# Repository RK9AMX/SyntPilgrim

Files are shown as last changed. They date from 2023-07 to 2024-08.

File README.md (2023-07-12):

### HF frequency synthesizer 'Pilgrim'
# Синтезатор ТПП "Пилигрим"
Разработка схемы и ПО: [Oleg 9](http://www.cqham.ru/forum/member.php?3781-Oleg-9)

Разработка печатной платы: [RK9AMX](http://www.cqham.ru/forum/member.php?2533-RK9AMX)

Обсуждение на [форуме](http://www.cqham.ru/forum/showthread.php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) cqham.ru

Синтезатор выполнен на базе микросхемы Si5351 и микроконтроллера PIC16F1787 (PIC16F887), индикатор LCD 16x2.

Файл прошивки для **PIC16F887** - 5351_PIC16F887_v07.hex

Для **PIC16F1787** - 5351_PIC16F1787_v07X.hex. С делителем на 8 для валкодера 5351_PIC16F1787_v08X_vlc div 8.hex

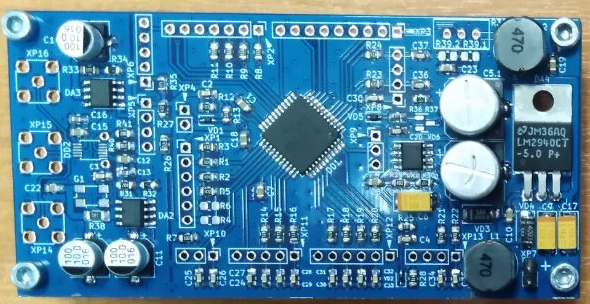
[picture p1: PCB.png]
PCB


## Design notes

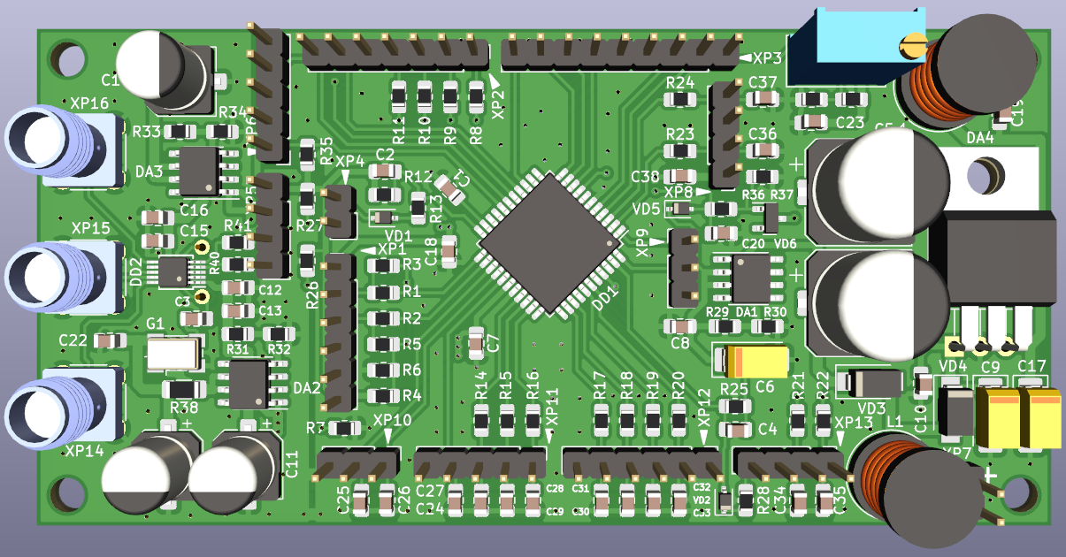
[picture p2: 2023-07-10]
top.png

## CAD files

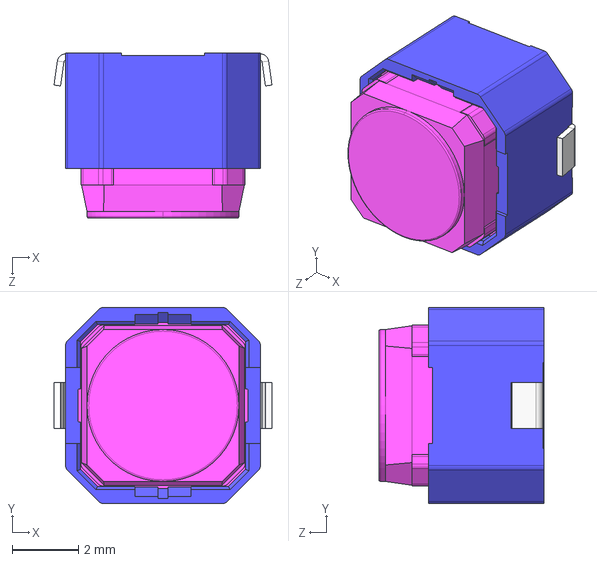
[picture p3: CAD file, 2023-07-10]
SKPMAM.STEP
6.60 x 5.94 x 5.00 mm

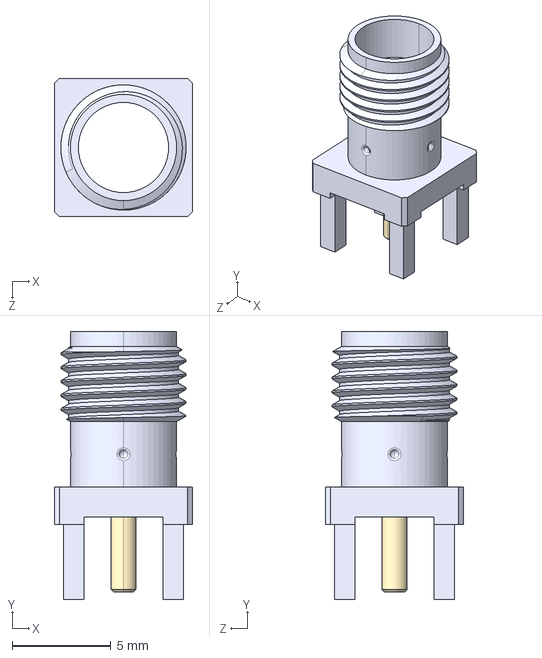
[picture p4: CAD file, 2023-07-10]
CON_SMA1.STEP
7.01 x 13.6 x 7.01 mm

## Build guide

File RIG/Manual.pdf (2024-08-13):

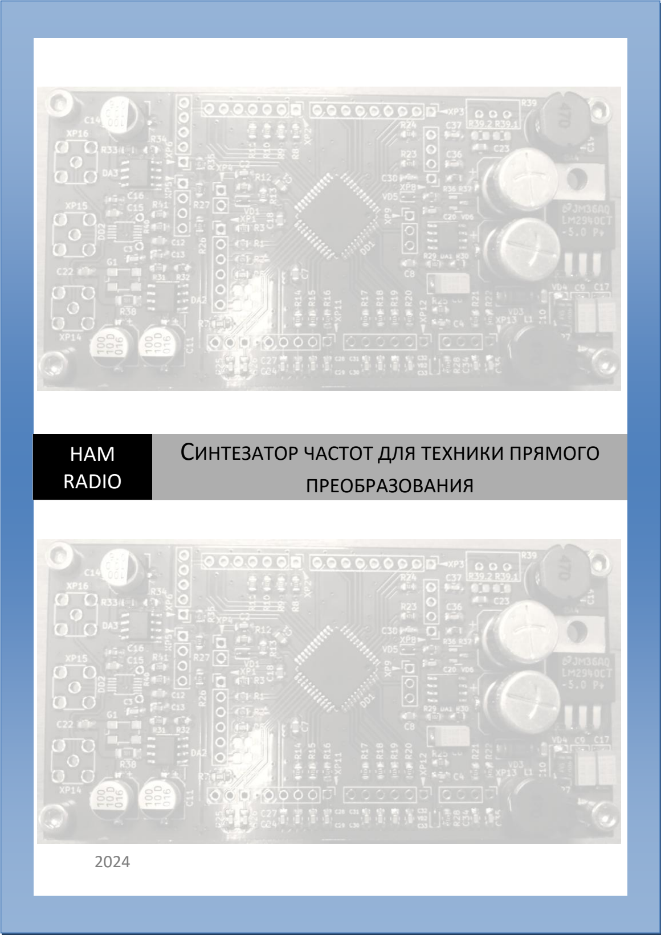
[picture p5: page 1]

2024

## HAM RADIO

## СИНТЕЗАТОР ЧАСТОТ ДЛЯ ТЕХНИКИ ПРЯМОГО

## ПРЕОБРАЗОВАНИЯ

2 | Синтезатор частот для техники прямого преобразования
| Оглавление

Введение
Синтезатор предназначен для применения в качестве гетеродина в трансивере или приёмнике прямого преобразования. Синтез частоты осуществляется микросхемой Si5351A. Перестройка частоты осуществляется валкодером.

Основные характеристики
- Напряжение питания: 9 - 12 В
- Потребляемый ток: 160 мА
- Диапазон синтезируемых частот: 12 кГц - 120 МГц
- Выходное сопротивление: 50 Ом
- Форма выходного напряжения: меандр
- Размах выходного напряжения: 3 В
- Умножение выходной частоты: 1, 2, 4 (Устанавливается в настройках)
- Индикатор: 16 сегментов, 2 строки
- Клавиатура: 12 кнопок (3 х 4)

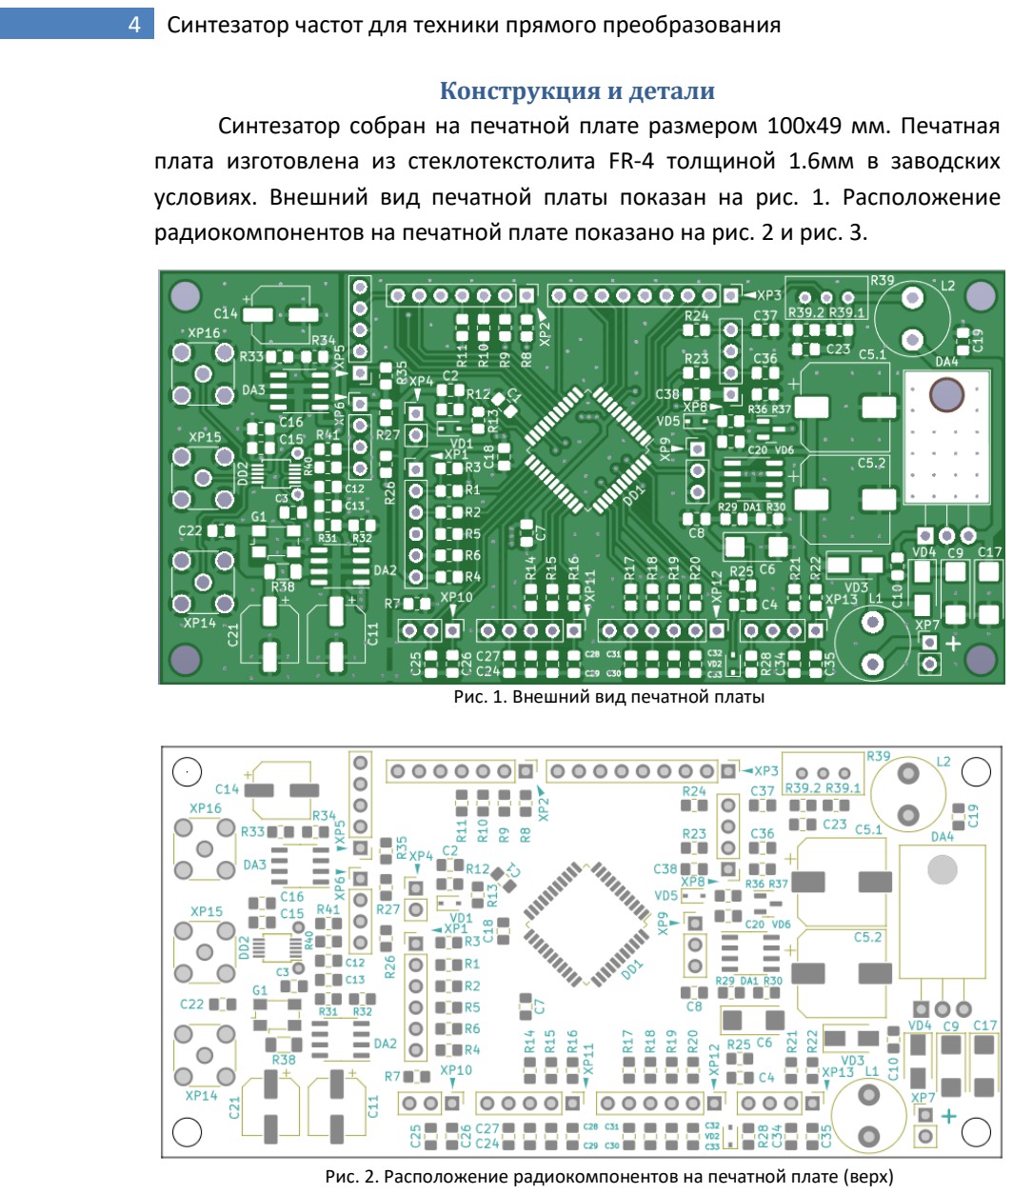
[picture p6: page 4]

Конструкция и детали
Синтезатор собран на печатной плате размером 100х49 мм. Печатная плата изготовлена из стеклотекстолита FR-4 толщиной 1.6мм в заводских условиях. Внешний вид печатной платы показан на рис. 1. Расположение радиокомпонентов на печатной плате показано на рис. 2 и рис. 3.

Рис. 1. Внешний вид печатной платы

Рис. 2. Расположение радиокомпонентов на печатной плате (верх)

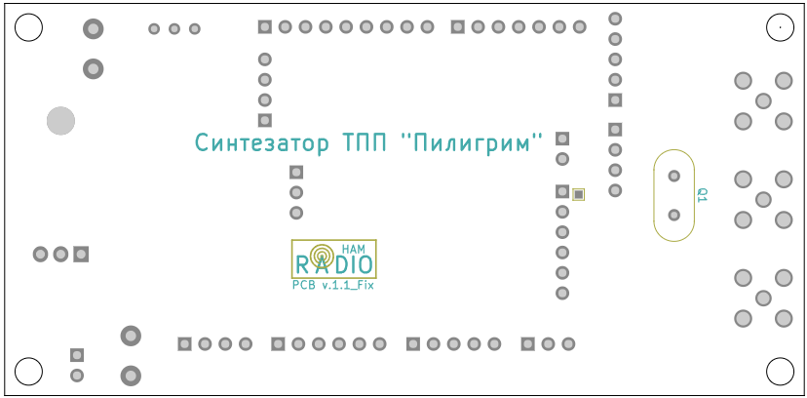
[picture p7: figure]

Рис. 3. Расположение радиокомпонентов на печатной плате (низ)

Все керамические конденсаторы SMD, типоразмер 0805. C6, C8, C17 – танталовые в корпусе 6032. С11, С14, С21 – электролитические SMD 6.3x7.7 мм. В качестве С5 применены два электролитических конденсатора суммарной эквивалентной емкостью около 1000 мкФ (C5.1 и C5.2) SMD исполнения 10х10 мм.

Все резисторы SMD, типоразмер 0805, кроме R38 – типоразмер 1206. Резистор R39 в корпусе 3296W – регулировка контрастности дисплея, может быть заменён на пару резисторов R39.1 и R39.2 типоразмера 0805. Если установлен резистор R39, то резисторы R39.1 и R 39.2 устанавливать не нужно, и наоборот.

Дроссели L1, L2 индуктивностью 20-50 мкГн и сопротивлением по постоянному току не более 1 Ом.

Диоды VD3, VD4 – любые на ток не менее 300 мА в корпусе SMA (DO-214AC). Диоды VD1, VD2, VD5 в корпусе SOD-323 с барьером шоттки. Стабилитрон VD6 в корпусе SOT-23.

Микросхемы:

- DA1-DA3 – LM317L в корпусе SO-8;
- DA4 - L7805 в корпусе TO-220;
- DD1 – PIC16F1787-I/PT в корпусе UQFN-40;
- DD2 – Si5351A-B-GT в корпусе MSOP-10.

В качестве генератора G1 можно применить кварцевый генератор в корпусе 5032 на частоту 25-27
МГц. Чтобы использовать внутренний генератор
Si5351 | на | печатной | плате | предусмотрено

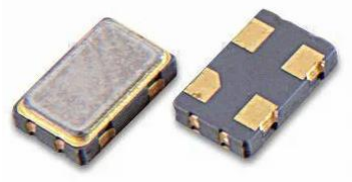
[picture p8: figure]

установочное место для кварцевого резонатора в корпусе HC49-S. Частота кварцевого резонатора должна быть 25-27 МГц. Если на плате предполагается установка кварцевого генератора, то кварцевый резонатор устанавливать не нужно, и наоборот.

Разъёмы X1-X13 – PLS на соответствующее количество контактов. Разъёмы X14-X16 – SMA вертикальные.

Клавиатура 12 копок (3х4) от телефона или самодельная с необходимым для конкретного исполнения передней панели расположением кнопок.

Индикатор жидкокристаллический 16 символов, 2
строки, | на | основе | контроллера | HD44780 | или
аналогичного. Можно применить любой, имеющий в обозначение цифры 1602. Например: WH1602A, SC1602,
HY-1602 и пр. Необходимо отметить, что у индикаторов
разных производителей может отличаться цоколёвка
разъема. Поэтому перед подключением следует ознакомиться с документацией производителя на применяемый индикатор.

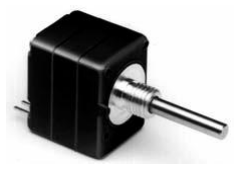
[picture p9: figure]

Валкодер может быть как самодельным, из
компьютерной | мыши | или | магнитным, | так | и
промышленного изготовления, генерирующий 32-512 импульсов на оборот. На разъёме X1 предусмотрено питание валкодера от 3.3 В и от 5 В.

Программирование микроконтроллера Программирование микроконтроллера на примере программатора PICkit3 (далее программатор) и программного обеспечениия MPLAB X IPE.

Перед началом работы с программатором необходимо провести следующие действия:

- Установить программное обеспечение MPLAB X IPE актуальной стабильной версии на ПК (драйвер программатора входит в комплект дистрибутива);
- Подключить программатор к ПК с помощью USB кабеля;
- Подключить программатор к плате изделия с помощью кабеля для внутрисхемного программирования.

Далее нужно запустить программу MPLAB X IPE (ярлык на рабочем столе). В главном меню программы выбрать пункт Settings -> Advanced mode. Появится окно (Рис. 4).

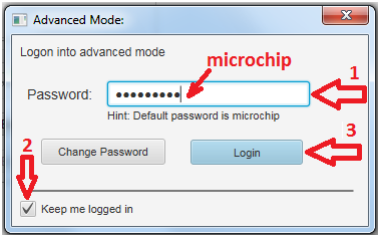
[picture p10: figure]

Рис. 4. Окно авторизации

В поле «Password» необходимо ввести пароль – microchip. Установить галочку напротив поля «Keep me logged in». Это позволит при последующих запусках программы не вводить пароль заново. Нажать кнопку «Login».

После этих действий в левой стороне окна программы должно появиться меню настроек.

Далее необходимо настроить программатор для работы с нужным микроконтроллером. Для этого в закладке «Operate» в выпадающем списке «Device» нужно выбрать микроконтроллер, с которым предполагается работа (Рис. 5). Для примера выбран PIC16F1787. Далее нужно нажать кнопку «Apply», а затем кнопку «Connect» и дождаться окончания подготовки программатора для работы с выбранным микроконтроллером.

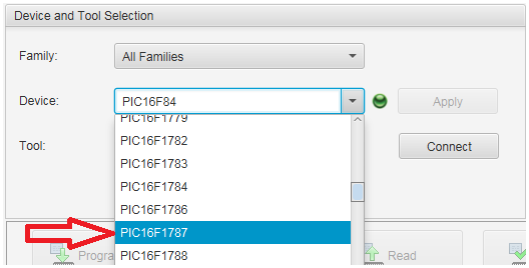
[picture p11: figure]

Рис. 5. Выбор микроконтроллера

В процессе подготовки появится окно предупреждения о том, что микроконтроллеры могут работать от напряжения 3.3V и это напряжение
необходимо | установить | в | соответствующих | настройках. | Иначе
микроконтроллер может выйти из строя (Рис. 6).

Напряжение питания микроконтроллера в схеме синтезатора 3.3 В.

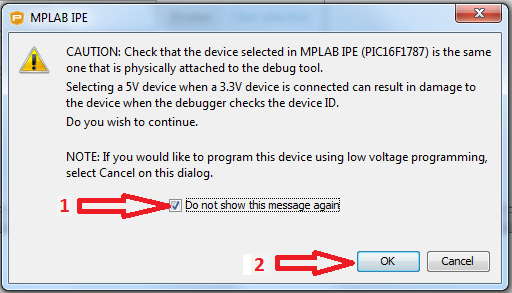
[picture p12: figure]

Рис. 6. Окно предупреждения

Нужно установить галочку напротив поля «Do not show this message again», чтобы далее об этом не предупреждать. Нажимаем кнопку «ОК» и считаем, что мы предупреждены о последствиях.

Прежде чем приступить к программированию необходимо провести настройку программатора. Для этого в меню настроек нужно выбрать вкладку «Power» (Рис. 7).

Рис. 7. Вкладка «Power»

Откроется вкладка «Power Settings». Если установить галочку напротив поля «Power Target circuit from Tool» (Рис. 8). Это позволит программировать синтезатор не подключая к нему внешнее питание. Однако рекомендуется программировать синтезатор задействовав его штатную схему питания. Поэтому указанную галочку необходимо снять.

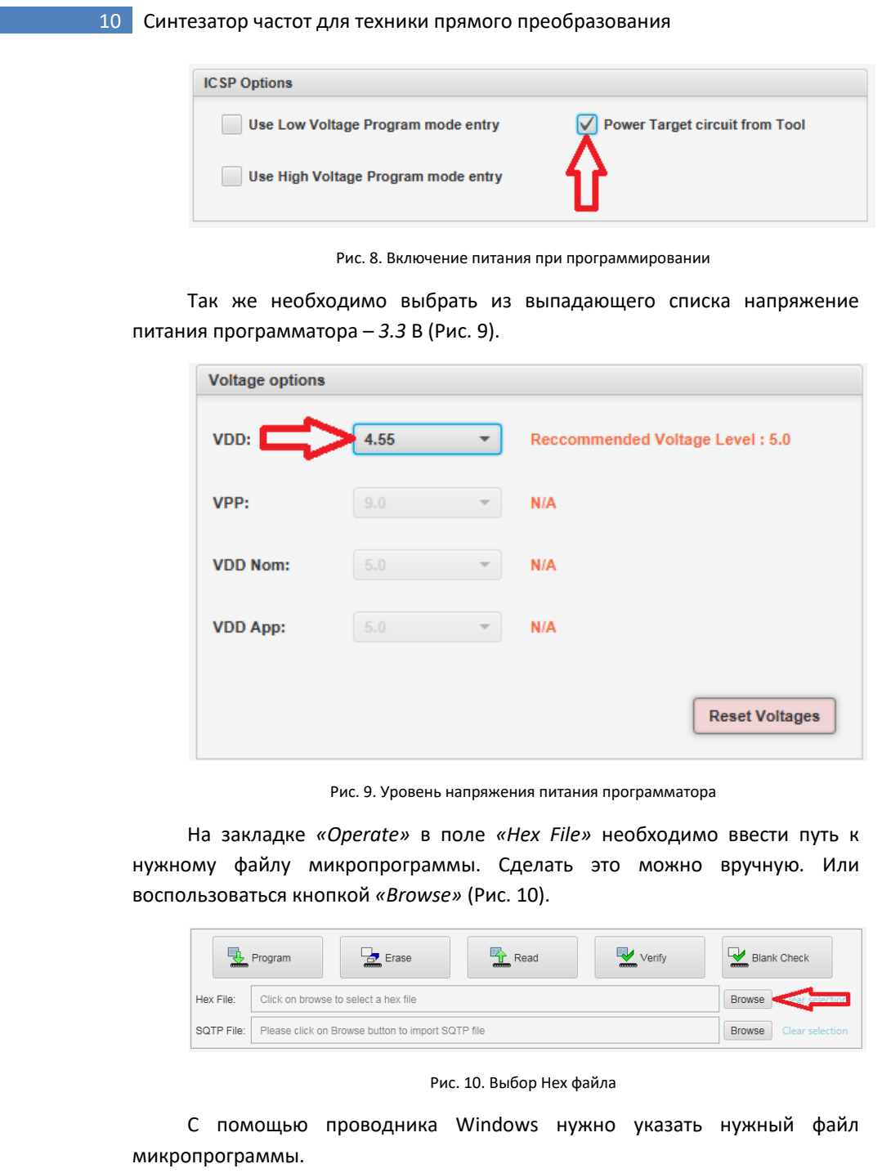
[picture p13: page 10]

Рис. 8. Включение питания при программировании

Так же необходимо выбрать из выпадающего списка напряжение питания программатора – 3.3 В (Рис. 9).

Рис. 9. Уровень напряжения питания программатора

На закладке «Operate» в поле «Hex File» необходимо ввести путь к нужному файлу микропрограммы. Сделать это можно вручную. Или воспользоваться кнопкой «Browse» (Рис. 10).

Рис. 10. Выбор Hex файла

С помощью проводника Windows нужно указать нужный файл микропрограммы.

Можно приступать к программированию микроконтроллера. Для этого нужно нажать кнопку «Program» на закладке «Operate» (Рис. 11).

Рис. 11. Кнопка «Program»

Об | успешном | завершении | операции | программирования
микроконтроллера будет свидетельствовать соответствующее сообщение в закладке «Output_IPE» (Рис. 12).

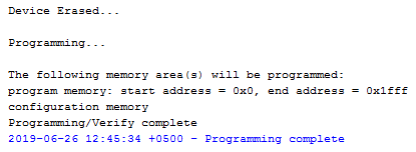
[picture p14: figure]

Рис. 12. Отчет программы

Назначение кнопок управления В режиме RX:

«1» Меняет местами действующий и запомненный набор установок диапазона. Набор установок включает в себя:

- Частоту
- Режим – CW или SSB
- Боковую полосу – верхнюю или нижнюю
- Статус аттенюатора, УВЧ и S-метра
- Включение дополнительного фильтра.

«2» Запоминает действующий набор установок диапазона.

«3» Включает режим RIT. В режиме RIT кнопка «1» включает режим XIT, кнопка «2» выключает режим RIT с сохранением текущей частоты, кнопка «3» выключает режим RIT с возвратом на частоту, которая была перед включением режима RIT.

«4» Переключает режимы cw / ssb.

«5» Переключает боковые полосы u / l.

«6» Включение / отключение S-метра.

«7» Управление УВЧ pre.

«8» Управление аттенюатором att.

«9» | Включение | дополнительного | фильтра. | Отображается | на
индикаторе точкой между режимом и боковой полосой.

«0» Вход в меню.

«*» Переключение диапазона вверх.

«#» Переключение диапазона вниз.

В режиме TX:

«1» Управление отображением безынерционной шкалы КБВ и мощности для настройки согласования передатчика с антенной.

Границы диапазонов по умолчанию Границы диапазонов можно устанавливать произвольно в меню синтезатора в переделах 1000000 – 31000000 Гц. Однако следует учитывать, чтобы частота на выходе синтезатора, которая равна:

не превышала 120000000 Гц.

Установленное по умолчанию распределение частот по диапазонам приведено в таблице 1.

Диапазон | Нижняя граница, Гц | Верхняя граница, Гц
0 | 1.799.000 | 2.001.000
1 | 3.499.000 | 3.801.000
2 | 6.999.000 | 7.201.000
3 | 10.099.000 | 10.151.000
4 | 13.999.000 | 14.351.000
5 | 18.049.000 | 18.171.000
6 | 20.999.000 | 21.451.000
7 | 24.889.000 | 24.991.000
8 | 27.999.000 | 29.701.000
GENE | 12.000 | 30.005.000
Таблица 1. Границы диапазонов по умолчанию

Ввод частоты с клавиатуры
Ввод частоты с клавиатуры используется в меню при установке границ диапазонов и других частотных установок.

Поддерживается сокращённый ввод. Например, чтобы ввести частоту 14.000.000 Гц достаточно набрать 14 → «#». Для ввода частоты 7.050.000 достаточно набрать 0705 → «#». Для ввода 1.893.210 нужно набрать 0189321 → «#».

Нажатие кнопки «*» в этом режиме перемещает курсор на одну позицию влево, обнуляя стоящую там цифру. Применяется для повторного ввода ошибочно набранной цифры.

Режим CW
В телеграфном режиме реализована функция сдвига частоты. Такое решение позволяет избавиться от помехи посредством переключения боковой полосы без потери приёма телеграфной станции. Допустим, включена верхняя боковая полоса, отображаемая на индикаторе частота будет выше выдаваемой синтезатором на величину CW shift. Значение CW shift устанавливается в настройках синтезатора равным средней частоте телеграфного фильтра. Далее в режиме CW при смене боковой полосы с верхней на нижнюю, частота синтезатора увеличивается на удвоенное значение CW shift. При смене боковой полосы с нижней на верхнюю, частота синтезатора уменьшается на удвоенное значение CW shift.

При переходе на передачу в телеграфном режиме, если в настройках синтезатора CW shift TX = On, выходная частота синтезатора становится равной отображаемой на экране, то есть частоте принимаемой станции, что позволяет формировать телеграфный сигнал непосредственно из выходного сигнала синтезатора.

Например, в настройках синтезатора CW shift = 700, CW shift TX = On, частота на выходе синтезатора 7004000 Гц, тогда в режиме CW, при включенной верхней боковой полосе на индикаторе будет отображена частота 7004700 Гц. Телеграфная станция, имеющая частоту 7004700 Гц будет приниматься с тоном 700 Гц (7004700 – 7004000 = 700). Если переключить боковую полосу с верхней на нижнюю, то частота на выходе синтезатора увеличится до 7005400 Гц и станция с частотой 7004700 Гц так же будет слышна с тоном 700 Гц (7005400 – 7004700 = 700). При переходе на передачу частота на выходе синтезатора в обоих случаях будет равна 7004700 Гц.

При установке умножения частоты синтезатора в 2 или 4 раза, во столько же умножится сдвиг выходной частоты и при последующем делении в цифровом фазовращателе смесителя примет нужное значение.

Режимы RIT и XIT
При включении режима RIT текущая частота запоминается и восстанавливается при переходе на передачу. В режиме приёма можно перестраивать частоту валкодером. Включение режима XIT меняет местами текущую и запомненную частоты и при переходе на передачу устанавливается частота, которая была в момент включения XIT.

Блокировка валкодера
Отключение валкодера осуществляется нажатием последовательности кнопок «0» → «2» (см. рис. 13). При блокировке валкодера перестройка
частоты | синтезатора | невозможна. | Однако, | остальные | функции
(переключение диапазонов, включение и отключение ATT, PRE и т.д.) доступны по нажатию соответствующих кнопок.

Рис. 13

Меню установок синтезатора Вызов меню осуществляется нажатием кнопки «0». Кнопкой «*» осуществляется перемещение курсора по пунктам меню, кнопкой «#» -выбор пункта на котором находится курсор (см. рис. 14).

Рис. 14

Назначение пунктов меню:

- F – установки синтезатора:
- XO F - установка значения частоты опорного генератора;
- Crystal cap – установка включения конденсаторов кварцевого резонатора;
- Si5151a addr – установка I

2
C адреса Si5351a;
- F out multiply – установка множителя для выходной частоты синтезатора, относительно отображаемой на индикаторе;
- CW shift - установка сдвига частоты при переходе в режим CW;
- CW shift TX – установка сдвига частоты при переходе на передачу в режиме CW.
- Vlc – установки валкодера:
- Val step – установка шага перестройки частоты валкодером;
- Val U ref – установка опорного напряжения компараторов валкодера.
- Val div – установка делителя шагов валкодера.
- BL – установка границ диапазонов;
- Io – выбор высокого или низкого логического уровня на выходах синтезатора att, pre, flt, cw, u / l при включении соответствующего режима. Активация режима отключения УВЧ pre TX off в режиме передачи.
- Sm – калибровка S-метра;
- Q – сохранение настроек и выход из меню.

Развёрнуто о некоторых настройках Частота настройки синтезатора валкодером будет изменяться на значение установленного в пункте меню «Val step» при каждом перепаде логического уровня на входах валкодера.

Установка опорного напряжения компараторов валкодера «Val U ref» актуальна при использовании самодельных валкодеров, не имеющих формирователя меандра на выходе оптопар. Например, изготовленных из компьютерной мыши. Опорное напряжение выставляется средним между значениями на выходах валкодера, когда фотоэлемент полностью освещён (отверстие в диске) и полностью затемнён (перегородка между отверстиями диска). Значение вычисляется по формуле:

Установка значения делителя шагов валкодера отличного от «1» позволит пропускать перепады логического уровня на входах валкодера. Например, при установке значения делителя «8», изменение частоты на индикаторе будет происходить только после восьмого перепада логического уровня.

В пункте меню «BL» можно задать нижнюю «Down» и верхнюю «Up» границы перестройки частоты синтезатора для каждого диапазона в пределах 1000000 – 31000000 Гц.

Выбор логических уровней для режимов att, pre, flt, cw, u осуществляется в пункте меню «Io» (см. рис. 15). Здесь можно настроить, какой логический уровень, высокий или низкий будет на выходе, при включении соответствующего режима. Например, если под буквой «u» выставить «H», то при верхней боковой полосе на выходе синтезатора USB/LSB синтезатора (контакт 3 разъёма XP11) будет напряжение логической единицы (3.3В), а при нижней боковой полосе напряжение логической единицы (0В). Если под режимом «u» выставить «L», то наоборот, при верхней боковой полосе на выходе USB/LSB будет логический ноль, а при нижней логическая единица. Аналогично для остальных выходов.

Рис. 15

Калибровка S-метра
При входе в режим калибровки индикатор приобретает вид изображённый на рис. 16.

Рис. 16

После | надписи | «Uadc» | отображается | величина | постоянного
напряжения, поступающего с детектора АРУ или детектора S-метра на вход АЦП синтезатора (контакт 4 разъёма XP11). Если нет необходимости менять настройки S-метра, то на этом этапе можно выйти из режима калибровки, нажав кнопку «*».

Для проведения калибровки нужно подать на вход приёмника или трансивера ВЧ напряжение, соответствующее показаниям S-метра и уровням указанными в столбце 3 таблицы 2. После установки напряжения соответствующего 1 баллу S-метра нужно нажать кнопку «#». Это действие сохранит калибровку и осуществит переход к следующему значению калибровки (см. рис. 17). При этом нужно подать ВЧ напряжение на вход приёмника соответствующее 2 баллам S-метра. Сохранение значения и
переход | к | следующей | уставке | осуществляется | кнопкой | «#».
Последовательность действий нужно повторить для всех калибровочных значений показаний S-метра. После S9+60dB происходит возврат в меню настроек синтезатора.

Рис. 17

Если функция S-метра не используется, то соответствующий вход нужно соединить с общим проводом синтезатора.

Уровень S-метра, балл | Уровень сигнала, dBm | Напряжение на входе (Rвх = 50 Ом), мкВ | Напряжение на входе (Rвх = 50 Ом), мкВ
1 | -121 | 0.2 | 0.24
2 | -115 | 0.4 | 0.49
3 | -109 | 0.8 | 0.98
4 | -103 | 1.6 | 1.9
5 | -97 | 3.2 | 3.9
6 | -91 | 6.3 | 7.7
7 | -85 | 12.6 | 15.4
8 | -79 | 25 | 30.7
9 | -73 | 50 | 61.3
9+10dB | -63 | 158 | 194
9+20dB | -53 | 500 | 612
9+30dB | -43 | 1580 | 1940
9+40dB | -33 | 5000 | 6120
9+50dB | -23 | 15800 | 19400
9+60dB | -13 | 50000 | 61200
Таблица 2. Соответствие уровней S-метра и уровней сигнала на входе приёмника

CAT интерфейс
В синтезаторе реализован обмен с компьютером по протоколу Kenwood (не полное соответствие, см. таблицу 3). Для взаимодействия с синтезатором в программах на ПК должны быть сделаны следующие установки:
- Модель трансивера: Kenwood TS-590;
- Скорость обмена: 57600 бод;
- Разрядность: 8 бит;
- Контроль чётности: нет;
- Стоповый бит: 1.

Команда управления состоит из двух букв, набора параметров и символа завершения команды (терминатора). Например, команда установки частоты синтезатора на 7 МГц будет состоять из элементов показанных на рис. Х

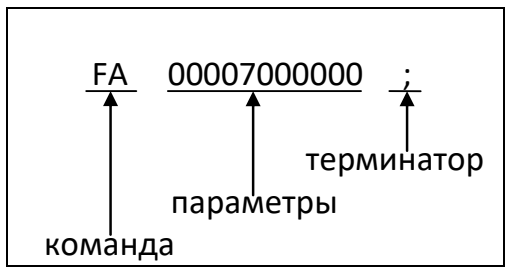
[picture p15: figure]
терминатор параметры команда

Рис. Х CAT команда

Система команд работает в режимах запрос-ответ, установка параметров. Например, команда:

- “FA00007000000;”- установка частоты синтезатора 7 МГц;
- “FA;” – запрос текущей частоты синтезатора;
- После запроса синтезатор выдаст ответ “FA00007000000;”.

В команде можно использовать как строчные, так и прописные буквы. Параметры команды используются для информации необходимой для выполнения требуемой команды. Параметры команды и количество цифр в команде предварительно определено. При настройке параметров необходимо следить за тем, чтобы не допускать ошибок. Для окончания команды используется терминатор - “;”. Его позиция в команде строго определена. Если синтаксис команды будет некорректным, то синтезатор вернёт ответ “?;”. Если возникнут ошибки в параметрах команды из-за некорректно принятых данных, то синтезатор вернёт ответ “E;”

Таблица 3. Перечень команд

BD/BU | Выбор диапазона | Параметры: P1 (Номер диапазона) 00: 1.8 МГц 01: 3.5 МГц 02: 7 МГц 03: 10 МГц 04: 14 МГц 05: 18 МГц 06: 21 МГц 07: 24 МГц 08: 28 МГц 09: GENE
Установка | 1 | 2 | 3 | 4 | 5 | 6 | 7 | 8 | 9 | 10
| B | U/D | P1 | P1 | ;
CH | Эмуляция вращение валкодера | Параметры: P1 0: Поворот валкодера на 1 шаг вверх. 1: Поворот валкодера на 1 шаг вниз.
Установка | 1 | 2 | 3 | 4 | 5 | 6 | 7 | 8 | 9 | 10
| C | H | P1 | ;
EX | Чтение и запись ячейки памяти (EEPROM) | Параметры: P1 000..255: Номер ячейки памяти P2 000..255: Значение ячейки памяти
Установка | 1 | 2 | 3 | 4 | 5 | 6 | 7 | 8 | 9 | 10
| E | X | P1 | P1 | P1 | P2 | P2 | P2 | ;
Запрос | 1 | 2 | 3 | 4 | 5 | 6 | 7 | 8 | 9 | 10
| E | X | P1 | P1 | P1 | ;
Ответ | 1 | 2 | 3 | 4 | 5 | 6 | 7 | 8 | 9 | 10
| E | X | P1 | P1 | P1 | P2 | P2 | P2 | ;

FA/FB | Установка и чтение частоты VFO-A (VFO-A = VFO-B) | Параметры: P1 - частота (11 цифр в Hz) Например, для частоты 14.195MHz формат будет такой 00014195000. Нули перед значением частоты обязательны.
Установка | 1 | 2 | 3 | 4 | 5 | 6 | 7 | 8 | 9 | 10
| F | A/B | P1 | P1 | P1 | P1 | P1 | P1 | P1 | P1
| 11 | 12 | 13 | 14 | 15 | 16 | 17 | 18 | 19 | 20
| P1 | P1 | P1 | ;
Запрос | 1 | 2 | 3 | 4 | 5 | 6 | 7 | 8 | 9 | 10
| F | A/B | ;
Ответ | 1 | 2 | 3 | 4 | 5 | 6 | 7 | 8 | 9 | 10
| F | A/B | P1 | P1 | P1 | P1 | P1 | P1 | P1 | P1
| 11 | 12 | 13 | 14 | 15 | 16 | 17 | 18 | 19 | 20
| P1 | P1 | P1 | ;
FL | Чтение и установка фильтра | Параметры: P1 0: Фильтр А 1: Фильтр Б
Установка | 1 | 2 | 3 | 4 | 5 | 6 | 7 | 8 | 9 | 10
| F | L | P1 | ;
Запрос | 1 | 2 | 3 | 4 | 5 | 6 | 7 | 8 | 9 | 10
| F | L | ;
Ответ | 1 | 2 | 3 | 4 | 5 | 6 | 7 | 8 | 9 | 10
| F | L | P1 | ;
FV | Чтение версии микропрограммного обеспечения | Параметры: P1 Чтение строки с версией программы. Например, для версии программы 1.10, ответ будет “FV1.10;”
Запрос | 1 | 2 | 3 | 4 | 5 | 6 | 7 | 8 | 9 | 10
| F | V | ;
Ответ | 1 | 2 | 3 | 4 | 5 | 6 | 7 | 8 | 9 | 10
| F | V | P1 | P1 | P1 | P1 | ;

IF | Чтение статуса синтезатора | Параметры: P1 Значение частоты 11 цифр (например: 00014155000 – 14.155kHz) P2 Пробел (5) P3 0: всегда 00000 P4 0: RIT выключена 1: RIT включена P5 0: XIT выключена 1: XIT включена P6 0: всегда 0 P7 0: всегда 00 P8 0: RX 1: TX P9 Режим модуляции: 3, 7: CW Остальные: SSB P10 0: всегда 0 P11 0: всегда 0 P12 0: всегда 0 P13 0: всегда 0 P14 0: всегда 00 P15 0: всегда 0
Запрос | 1 | 2 | 3 | 4 | 5 | 6 | 7 | 8 | 9 | 10
| I | F | ;
Ответ | 1 | 2 | 3 | 4 | 5 | 6 | 7 | 8 | 9 | 10
| I | F | P1 | P1 | P1 | P1 | P1 | P1 | P1 | P1
| 11 | 12 | 13 | 14 | 15 | 16 | 17 | 18 | 19 | 20
| P1 | P1 | P1 | P2 | P2 | P2 | P2 | P2 | P3 | P3
| 21 | 22 | 23 | 24 | 25 | 26 | 27 | 28 | 29 | 30
| P3 | P3 | P3 | P4 | P5 | P6 | P7 | P7 | P8 | P9
| 31 | 32 | 33 | 34 | 35 | 36 | 37 | 38 | 39 | 40
| P10 | P11 | P12 | P13 | P14 | P14 | P15 | ;
LK | Чтение и установка статуса блокировки валкодера | Параметры: P1 0: Блокировка вкл. 1: Блокировка откл. P2 0: всегда 0
Установка | 1 | 2 | 3 | 4 | 5 | 6 | 7 | 8 | 9 | 10
| L | K | P1 | P2 | ;
Запрос | 1 | 2 | 3 | 4 | 5 | 6 | 7 | 8 | 9 | 10
| L | K | ;
Ответ | 1 | 2 | 3 | 4 | 5 | 6 | 7 | 8 | 9 | 10
| L | K | P1 | P2 | ;

MD | Чтение и установка режима модуляции | Параметры: P1 0: Нет 1: LSB 2: USB 3: CW 4: Нет 5: Нет 6: Нет 7: CW-R 8: Нет 9: Нет
Установка | 1 | 2 | 3 | 4 | 5 | 6 | 7 | 8 | 9 | 10
| M | D | P1 | ;
Запрос | 1 | 2 | 3 | 4 | 5 | 6 | 7 | 8 | 9 | 10
| M | D | ;
Ответ | 1 | 2 | 3 | 4 | 5 | 6 | 7 | 8 | 9 | 10
| M | D | P1 | ;
PA | Чтение и установка статуса предусилителя | Параметры: P1 0: предусилитель откл. 1: предусилитель вкл. P2 0: всегда 0
Установка | 1 | 2 | 3 | 4 | 5 | 6 | 7 | 8 | 9 | 10
| P | A | P1 | ;
Запрос | 1 | 2 | 3 | 4 | 5 | 6 | 7 | 8 | 9 | 10
| P | A | ;
Ответ | 1 | 2 | 3 | 4 | 5 | 6 | 7 | 8 | 9 | 10
| P | A | P1 | P2 | ;
RA | Чтение и установка статуса аттенюатора | Параметры: P1 00: аттенюатор откл. 01: аттенюатор вкл. P2 0: всегда 00
Установка | 1 | 2 | 3 | 4 | 5 | 6 | 7 | 8 | 9 | 10
| R | A | P1 | P1 | ;
Запрос | 1 | 2 | 3 | 4 | 5 | 6 | 7 | 8 | 9 | 10
| R | A | ;
Ответ | 1 | 2 | 3 | 4 | 5 | 6 | 7 | 8 | 9 | 10
| R | A | P1 | P1 | P2 | P2 | ;
RM | Чтение значения КСВ | Параметры: P1 1: всегда 1 P2 0010…0099: Значение КСВ Например, при КСВ = 1.3 ответ будет “RM10013;”
Запрос | 1 | 2 | 3 | 4 | 5 | 6 | 7 | 8 | 9 | 10
| R | M | ;
Ответ | 1 | 2 | 3 | 4 | 5 | 6 | 7 | 8 | 9 | 10
| R | M | P1 | P2 | P2 | P2 | P2 | ;

RT | Чтение и установка статуса расстройки (RIT) | Параметры: P1 0: RIT откл.
| 1 | 2 | 3 | 4 | 5 | 6 | 7 | 8 | 9 | 10
| R | T | P1 | ; | | | | | | | 1: RIT вкл. Установка
Запрос | 1 | 2 | 3 | 4 | 5 | 6 | 7 | 8 | 9 | 10
| R | T | ;
Ответ | 1 | 2 | 3 | 4 | 5 | 6 | 7 | 8 | 9 | 10
| R | T | P1 | ;
RX | Установка режима «приём» | Параметры: Нет параметров.
Установка | 1 | 2 | 3 | 4 | 5 | 6 | 7 | 8 | 9 | 10
| R | X | ;
SM | Чтение значения S-метра | Параметры: P1 0: всегда 0 P2 0000..0030: показания S-метра
Запрос | 1 | 2 | 3 | 4 | 5 | 6 | 7 | 8 | 9 | 10
| S | M | P1 | ;
Ответ | 1 | 2 | 3 | 4 | 5 | 6 | 7 | 8 | 9 | 10
| S | M | P1 | P2 | P2 | P2 | P2 | ;
SR | Рестарт синтезатора | Параметры: P1 0: всегда 1
Установка | 1 | 2 | 3 | 4 | 5 | 6 | 7 | 8 | 9 | 10
| S | R | P1 | ;
TX | Установка режима «передача» | Параметры: P1
| 1 | 2 | 3 | 4 | 5 | 6 | 7 | 8 | 9 | 10
| T | X | P1 | ; | | | | | | | 0: всегда 0 Установка
XT | Чтение и установка статуса расстройки (XIT) | Параметры: P1 0: XIT откл.
| 1 | 2 | 3 | 4 | 5 | 6 | 7 | 8 | 9 | 10
| X | T | P1 | ; | | | | | | | 1: XIT вкл. Установка
Запрос | 1 | 2 | 3 | 4 | 5 | 6 | 7 | 8 | 9 | 10
| X | T | ;
Ответ | 1 | 2 | 3 | 4 | 5 | 6 | 7 | 8 | 9 | 10
| X | T | P1 | ;

RIG Pilgrim – общее описание программы Программа RIG Pilgrim (далее программа) предназначена для управления и настройки синтезатора. Управление и настройка синтезатора осуществляется по CAT интерфейсу. Система команд интерфейса описана в этом документе ранее. Программа позволяет управлять частотой (изменять в пределах диапазона, переключать диапазоны), аттенюатором, УВЧ, модуляцией и др. Из программы возможны чтение и запись памяти EEPROM для настройки параметров синтезатора. Программа не требует установки. Однако, её следует размещать в отдельном каталоге. В этом же каталоге буду храниться настройки программы и языковые пакеты.

RIG Pilgrim – внешний вид и описание интерфейса Внешний вид окна при запуске программы показан на рис. 18.

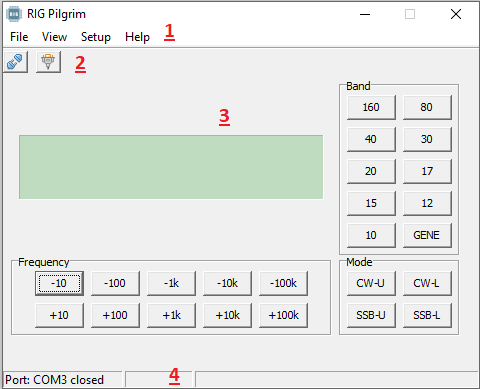
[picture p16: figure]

Рис. 18. Внешний вид программы при запуске

Окно программы делится на:

1. Основное меню;
2. Панель инструментов;
3. Панель управления;
4. Строку состояния.

Из основного меню доступно управление всеми функциями программы. Функции открытия и настройки COM порта для удобства вынесены на панель инструментов. На панели управления, после успешного подключения к синтезатору, отображается текущее синтезатора и активируются кнопки управления синтезатором.

RIG Pilgrim – настройка COM порта Для настройки COM порта выберите в меню → Setup → Serial port или

нажмите соответствующую кнопку Port Settings на панели инструментов. Появится окно установок COM порта (см. рис. 19).

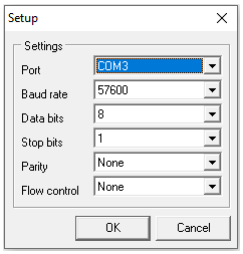
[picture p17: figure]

Рис. 19. Установки COM порта

Здесь нужно выбрать COM порт (виртуальный COM порт), к которому подключен трансивер. Скорость обмена нужно установить 57600 бод. Остальные установки порта оставить по умолчанию.

Если COM порт настроен правильно и нет неисправностей с

подключением, то после нажатия кнопки Open Port (меню → File → Open Port) произойдёт подключение трансивера к компьютеру и начнётся обмен по CAT интерфейсу.

RIG Pilgrim – элементы панели управления После успешного подключения окно программы примет вид показанный на рис. 20.

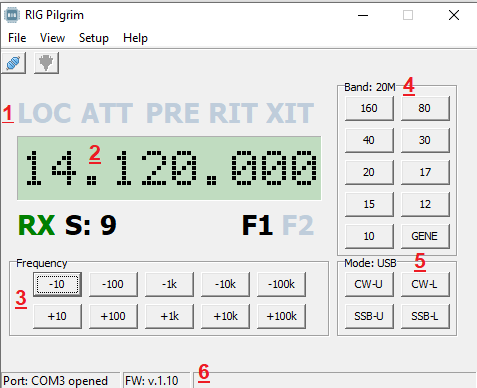
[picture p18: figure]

Рис. 20. Элементы панели управления

1. Индикация и управление функциями трансивера. Щелчок мыши по надписи приведёт к активации / деактивации выбранной функции. Например, клик мыши по надписи LOC приведёт к блокировке изменения частоты (отключению валкодера). Клик мыши по надписи RX переведёт трансивер на передачу. Надпись при этом поменяется на TX. Активация XIT невозможна, пока не будет активирована RIT.
2. Индикация установленной частоты. Частоту можно изменять колёсиком мыши, если указатель мыши находится внутри окна программы.
3. Кнопки изменения частоты.
4. Кнопки выбора диапазона.
5. Кнопки выбора модуляции и боковой полосы.
6. Строка состояния отображает открытый COM порт, версию прошивки и ошибки, возникающие при обмене командами. Если ошибок нет, то поле остаётся не заполненное. Появление ошибок свидетельствует о ненадёжном соединении трансивера с ПК.

RIG Pilgrim – элементы панели установок синтезатора Чтобы перейти к виду программы с установками синтезатора выберите пункт меню → View → RIG configuration, при этом окно программы примет вид изображённый на рис. 21.

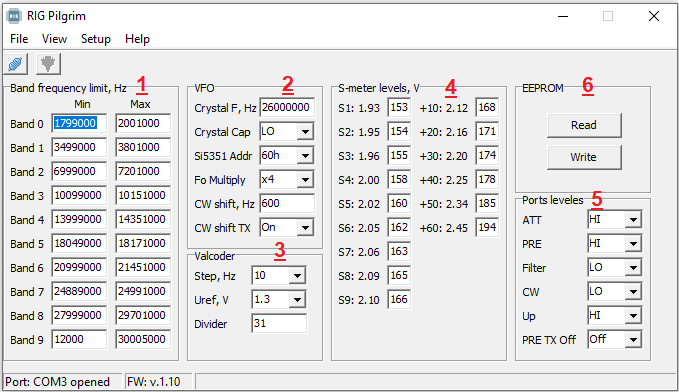
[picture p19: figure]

Рис. 21. Панель установок синтезатора

1. Установка границ диапазонов.
2. Установки гетеродина и опорного генератора.
3. Установки валкодера.
4. Константы уставок S-метра. Градуировку S-метра удобнее производить через меню синтезатора.
5. Установка активных уровней портов.
6. Кнопки чтения и записи установок в память синтезатора.

При выборе вида программы с панелью установок синтезатора происходит чтение EEPROM. Пока читается EEPROM, доступ к функциям программы недоступен.

Сохранить в файл или загрузить из файла установки синтезатора можно выбрав соответствующий пункт меню File. Файлы установок имеют расширение .cfr.

Возврат окна программы к виду панели управления осуществляется выбором пункта меню → View → CAT mode.

При изменении установок синтезатора будьте внимательны! Если вы не понимаете как нужно изменять установки, то не следует этого делать.

RIG Pilgrim – прочие функции Чтобы изменить языковые настройки нужно выбрать пункт меню → Setup → Language. Программа поддерживает два языковых пакета: Русский и English. Файлы с языковыми пакетами должны находиться в папке с программой.

Выбор пункта меню → Help → Manual откроет данное руководство. Файл руководства должен находиться в папке с программой.

Версия документа и история изменений

Текущая версия документа: v. 1

Версия документа v.1

Дата создания документа: 09.08.2024

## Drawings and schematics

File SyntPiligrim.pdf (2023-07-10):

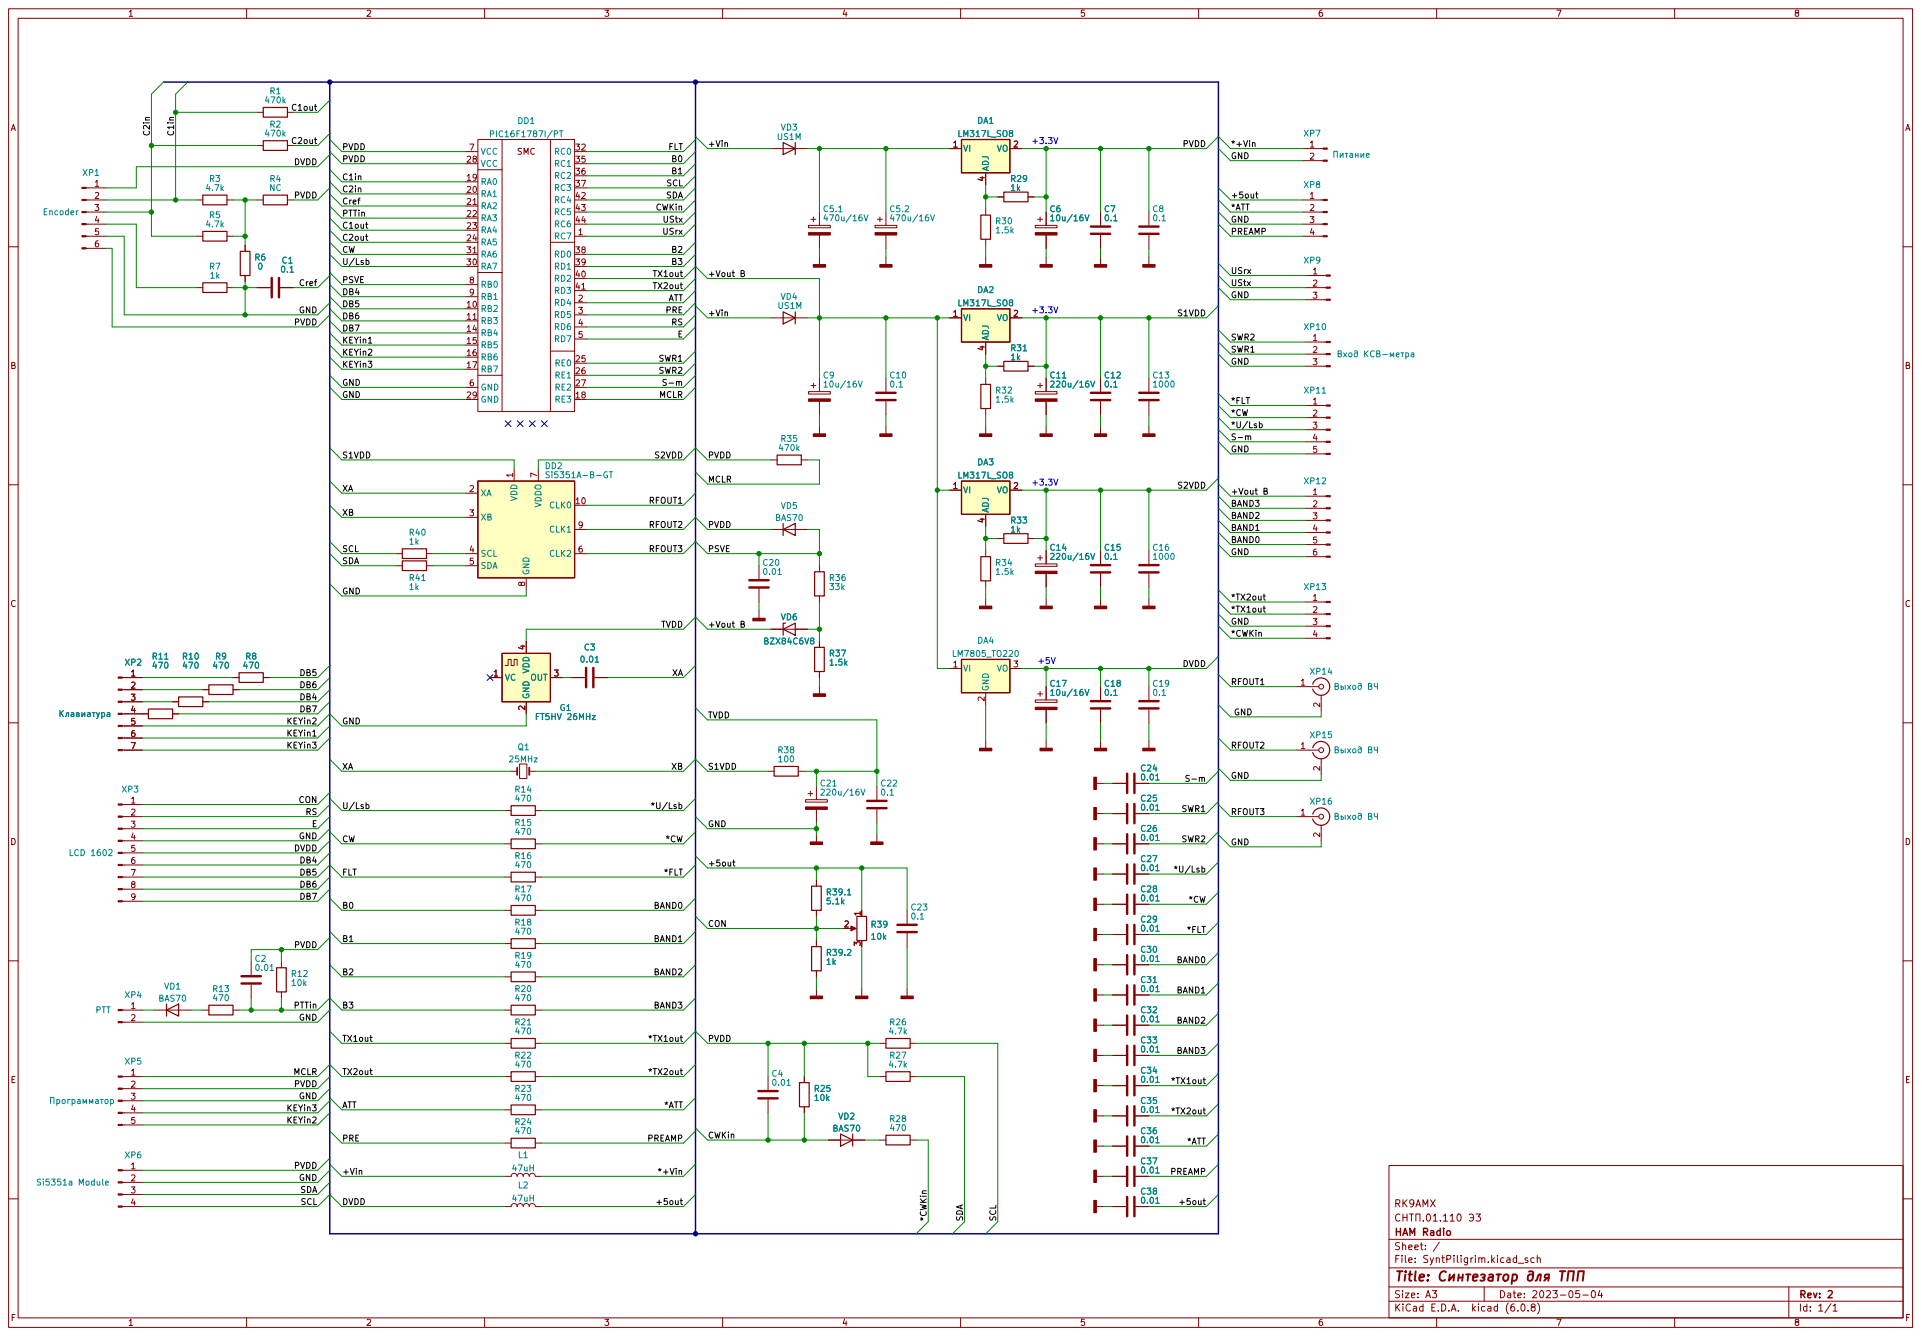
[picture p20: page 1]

File: SyntPiligrim.kicad_sch Sheet: / HAM Radio

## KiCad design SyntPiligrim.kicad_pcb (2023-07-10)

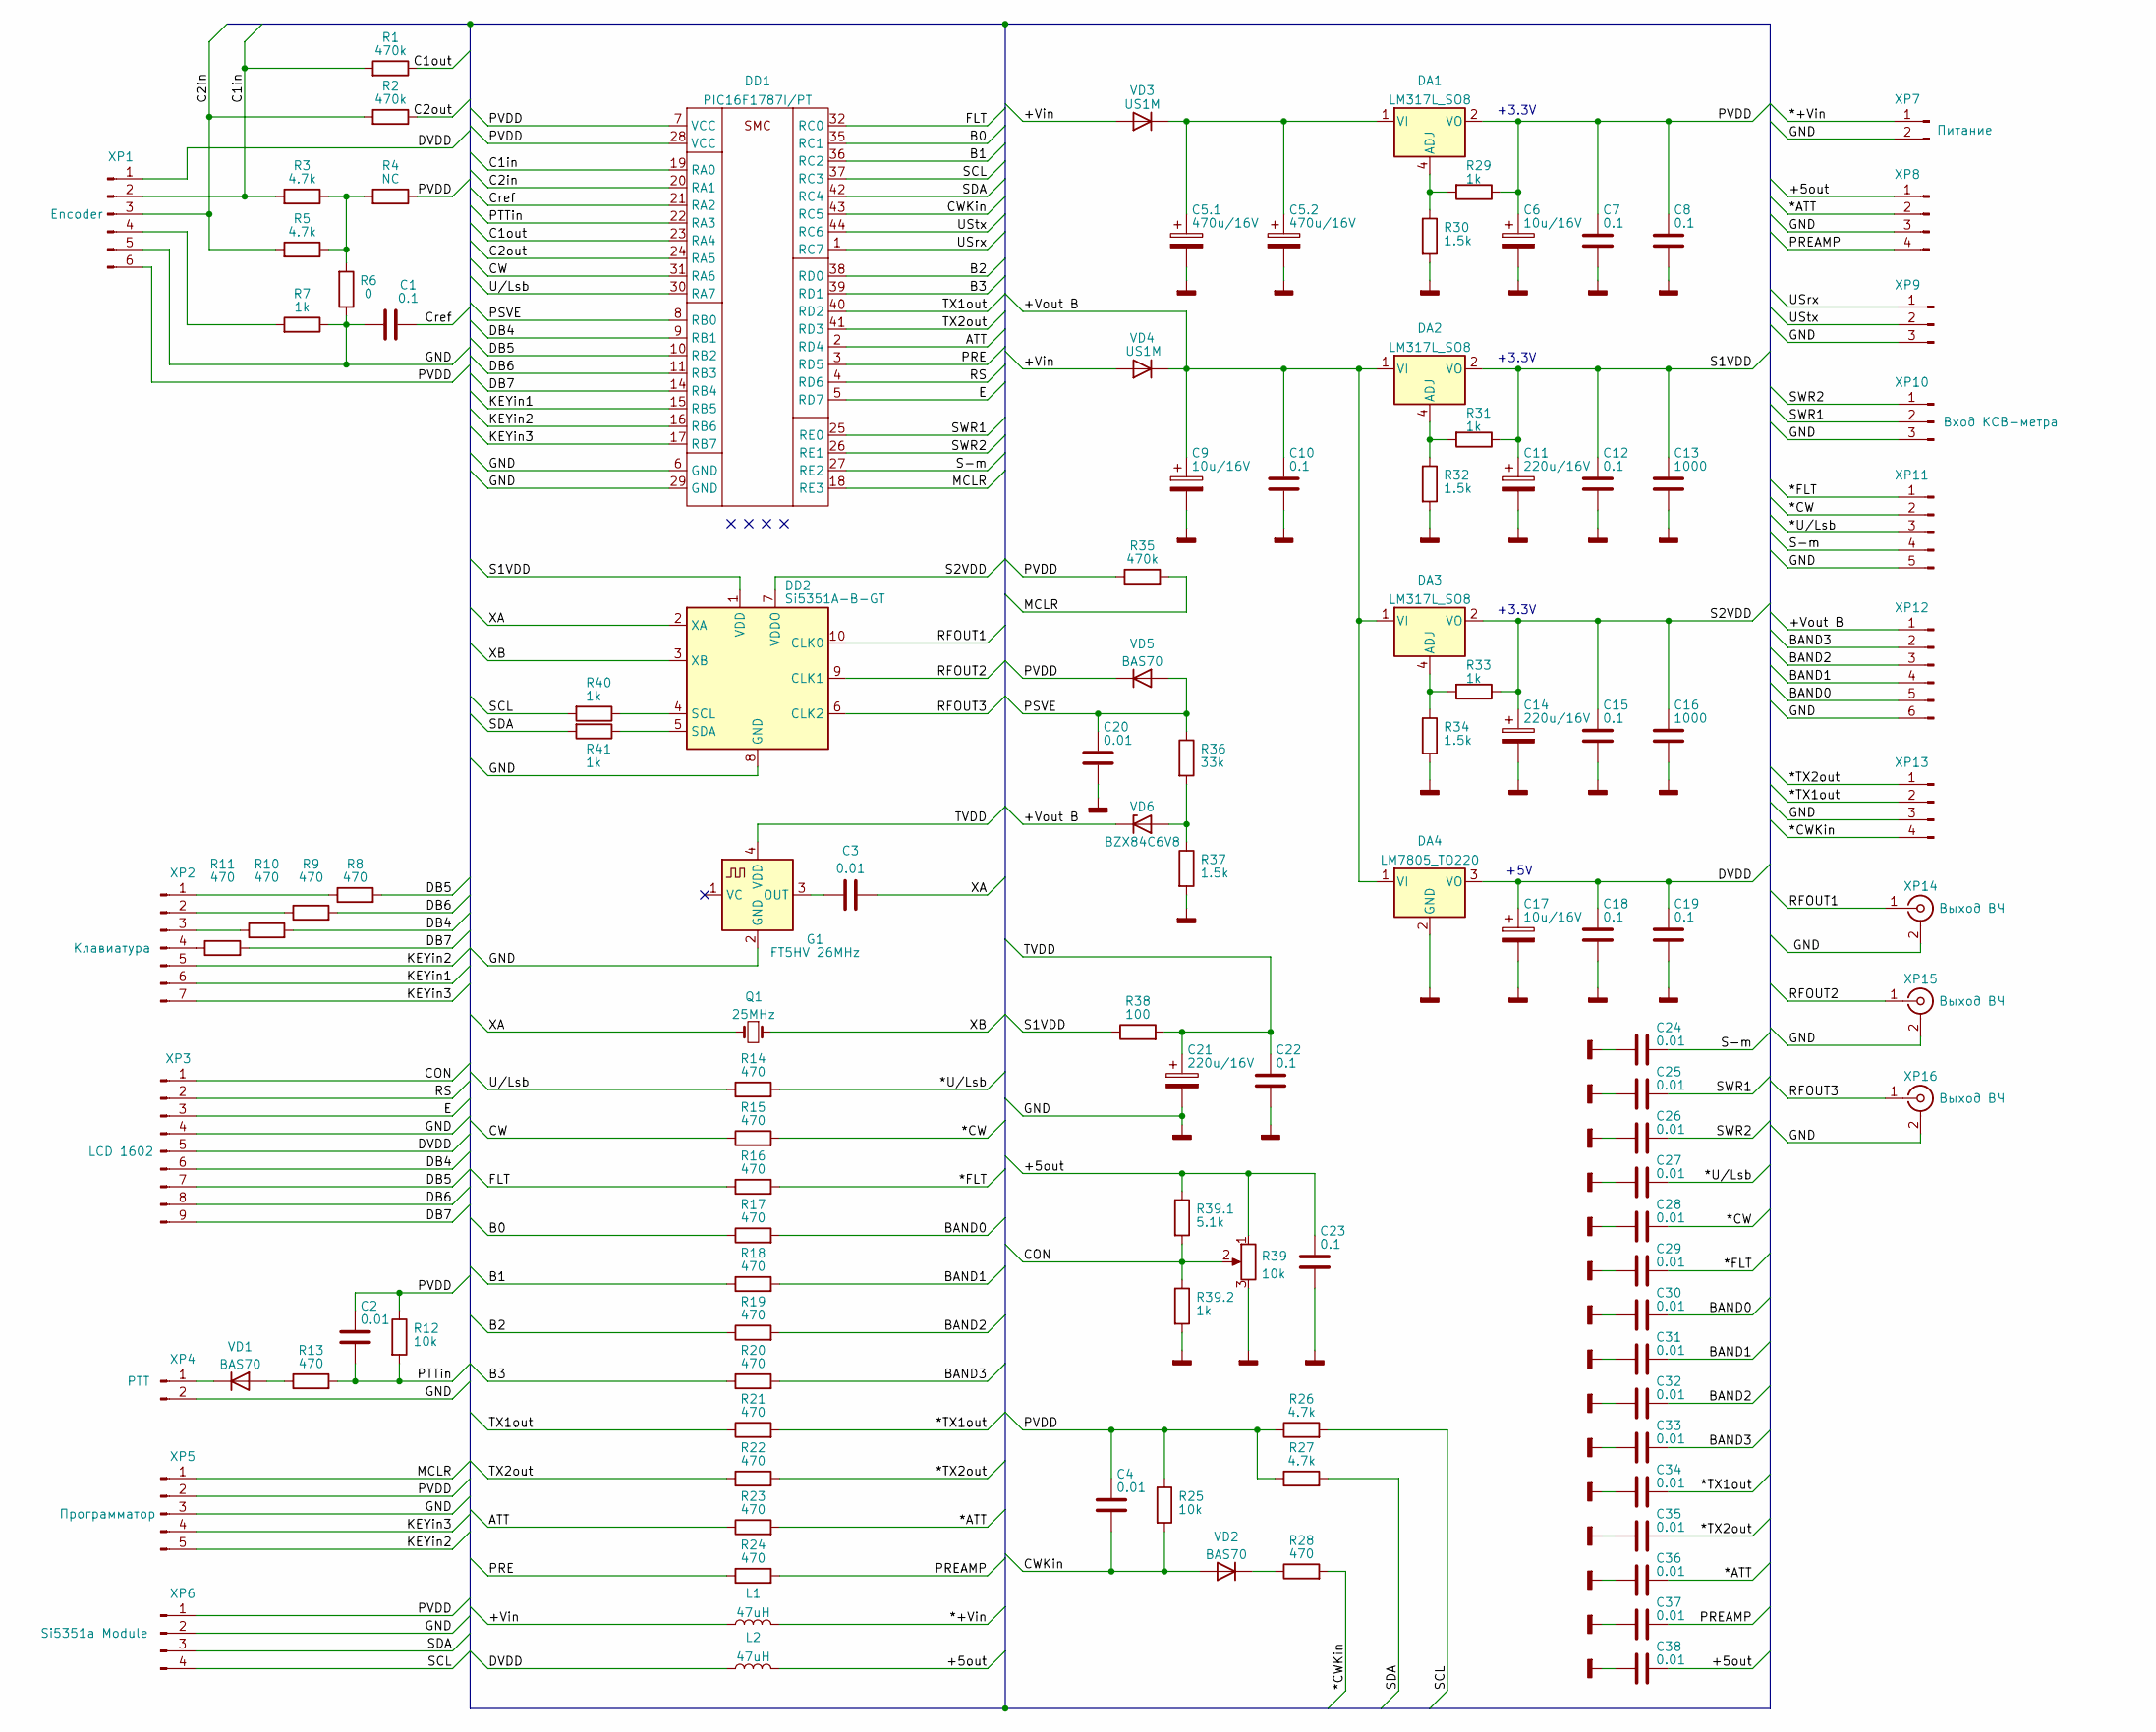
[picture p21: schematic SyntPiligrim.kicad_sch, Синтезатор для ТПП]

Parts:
C1, C7, C8, C10, C12, C15, C18, C19, C22, C23: 0.1; C_0805_2012Metric_Pad1.18x1.45mm_HandSolder
C2, C3, C4, C20, C24, C25, C26, C27, C28, C29, C30, C31, C32, C33, C34, C35, C36, C37, C38: 0.01; C_0805_2012Metric_Pad1.18x1.45mm_HandSolder
C5.1, C5.2: 470u/16V; CP_Elec_10x10
C6, C9, C17: 10u/16V; CP_EIA-6032-28_Kemet-C_Pad2.25x2.35mm_HandSolder
C11, C14, C21: 220u/16V; CP_Elec_6.3x7.7
C13, C16: 1000; C_0805_2012Metric_Pad1.18x1.45mm_HandSolder
DA1, DA2, DA3: LM317L_SO8; SOIC-8_3.9x4.9mm_P1.27mm
DA4: LM7805_TO220; TO-220-3_Horizontal_TabDown
DD1: PIC16F1787I/PT; LQFP-44_10x10mm_P0.8mm
DD2: Si5351A-B-GT; MSOP-10_3x3mm_P0.5mm
G1: FT5HV 26MHz; Oscillator_SMD_Fox_FT5H_5.0x3.2mm
L1, L2: 47uH; L_Radial_D8.7mm_P5.00mm_Fastron_07HCP
Q1: 25MHz; Crystal_HC49-4H_Vertical
R1, R2, R35: 470k; R_0805_2012Metric_Pad1.20x1.40mm_HandSolder
R3, R5, R26, R27: 4.7k; R_0805_2012Metric_Pad1.20x1.40mm_HandSolder
R4: NC; R_0805_2012Metric_Pad1.20x1.40mm_HandSolder
R6: 0; R_0805_2012Metric_Pad1.20x1.40mm_HandSolder
R7, R29, R31, R33, R39.2, R40, R41: 1k; R_0805_2012Metric_Pad1.20x1.40mm_HandSolder
R8, R9, R10, R11, R13, R14, R15, R16, R17, R18, R19, R20, R21, R22, R23, R24, R28: 470; R_0805_2012Metric_Pad1.20x1.40mm_HandSolder
R12, R25: 10k; R_0805_2012Metric_Pad1.20x1.40mm_HandSolder
R30, R32, R34, R37: 1.5k; R_0805_2012Metric_Pad1.20x1.40mm_HandSolder
R36: 33k; R_0805_2012Metric_Pad1.20x1.40mm_HandSolder
R38: 100; R_1206_3216Metric_Pad1.30x1.75mm_HandSolder
R39: 10k; Potentiometer_Bourns_3296W_Vertical
R39.1: 5.1k; R_0805_2012Metric_Pad1.20x1.40mm_HandSolder
VD1, VD2, VD5: BAS70; D_SOD-323
VD3, VD4: US1M; D_SMA
VD6: BZX84C6V8; SOT-23
XP1: Encoder; PinHeader_1x06_P2.54mm_Vertical
XP2: Клавиатура; PinHeader_1x07_P2.54mm_Vertical
XP3: LCD 1602; PinHeader_1x09_P2.54mm_Vertical
XP4: PTT; PinHeader_1x02_P2.54mm_Vertical
XP5: Программатор; PinHeader_1x05_P2.54mm_Vertical
XP6: Si5351a Module; PinHeader_1x04_P2.54mm_Vertical
XP7: Питание; PinHeader_1x02_P2.54mm_Vertical
XP8, XP13: c; PinHeader_1x04_P2.54mm_Vertical
XP9: Conn_01x03_Male; PinHeader_1x03_P2.54mm_Vertical
XP10: Вход КСВ-метра; PinHeader_1x03_P2.54mm_Vertical
XP11: c; PinHeader_1x05_P2.54mm_Vertical
XP12: c; PinHeader_1x06_P2.54mm_Vertical
XP14, XP15, XP16: Выход ВЧ; SMA_Wurth_60312002114503_Vertical

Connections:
/*+Vin: L1.2, XP7.1
/*ATT: C36.1, R23.2, XP8.2
/*CW: C28.1, R15.2, XP11.2
/*CWKin: R28.2, XP13.4
/*FLT: C29.1, R16.2, XP11.1
/*TX1out: C34.1, R21.2, XP13.2
/*TX2out: C35.1, R22.2, XP13.1
/*U/Lsb: C27.1, R14.2, XP11.3
/+5out: C23.1, C38.1, L2.2, R39.1, R39.1.1, XP8.1
/+Vin: L1.1, VD3.2 (A), VD4.2 (A)
/+Vout B: C9.1, C10.1, DA2.1 (VI), DA3.1 (VI), DA4.1 (VI), VD4.1 (K), VD6.3 (K), XP12.1
/ATT: DD1.2 (RD4), R23.1
/B0: DD1.35 (RC1), R17.1
/B1: DD1.36 (RC2), R18.1
/B2: DD1.38 (RD0), R19.1
/B3: DD1.39 (RD1), R20.1
/BAND0: C30.1, R17.2, XP12.5
/BAND1: C31.1, R18.2, XP12.4
/BAND2: C32.1, R19.2, XP12.3
/BAND3: C33.1, R20.2, XP12.2
/C1in: DD1.19 (RA0), R1.2, R3.2, XP1.2
/C1out: DD1.23 (RA4), R1.1
/C2in: DD1.20 (RA1), R2.2, R5.2, XP1.3
/C2out: DD1.24 (RA5), R2.1
/CON: R39.2, R39.1.2, R39.2.1, XP3.1
/CW: DD1.31 (RA6), R15.1
/CWKin: C4.2, DD1.43 (RC5), R25.2, VD2.2 (A)
/Cref: C1.2, DD1.21 (RA2)
/DB4: DD1.9 (RB1), R10.2, XP3.6
/DB5: DD1.10 (RB2), R8.2, XP3.7
/DB6: DD1.11 (RB3), R9.2, XP3.8
/DB7: DD1.14 (RB4), R11.2, XP3.9
/DVDD: C17.1, C18.1, C19.1, DA4.3 (VO), L2.1, XP1.1, XP3.5
/E: DD1.5 (RD7), XP3.3
/FLT: DD1.32 (RC0), R16.1
/KEYin1: DD1.15 (RB5), XP2.6
/KEYin2: DD1.16 (RB6), XP2.5, XP5.5
/KEYin3: DD1.17 (RB7), XP2.7, XP5.4
/MCLR: DD1.18 (RE3), R35.2, XP5.1
/PRE: DD1.3 (RD5), R24.1
/PREAMP: C37.1, R24.2, XP8.4
/PSVE: C20.1, DD1.8 (RB0), R36.1, VD5.2 (A)
/PTTin: C2.2, DD1.22 (RA3), R12.2, R13.2
/PVDD: C2.1, C4.1, C6.1, C7.1, C8.1, DA1.2 (VO), DA1.3 (VO), DA1.6 (VO), DA1.7 (VO), DD1.7 (VCC), DD1.28 (VCC), R4.1, R12.1, R25.1, R26.1, R27.1, R29.1, R35.1, VD5.1 (K), XP1.6, XP5.2, XP6.1
/RFOUT1: DD2.10 (CLK0), XP14.1 (In)
/RFOUT2: DD2.9 (CLK1), XP15.1 (In)
/RFOUT3: DD2.6 (CLK2), XP16.1 (In)
/RS: DD1.4 (RD6), XP3.2
/S1VDD: C11.1, C12.1, C13.1, DA2.2 (VO), DA2.3 (VO), DA2.6 (VO), DA2.7 (VO), DD2.1 (VDD), R31.1, R38.1
/S2VDD: C14.1, C15.1, C16.1, DA3.2 (VO), DA3.3 (VO), DA3.6 (VO), DA3.7 (VO), DD2.7 (VDDO), R33.1
/S-m: C24.1, DD1.27 (RE2), XP11.4
/SCL: DD1.37 (RC3), R26.2, R40.2, XP6.4
/SDA: DD1.42 (RC4), R27.2, R41.2, XP6.3
/SWR1: C25.1, DD1.25 (RE0), XP10.2
/SWR2: C26.1, DD1.26 (RE1), XP10.1
/TVDD: C21.1, C22.1, G1.4 (VDD), R38.2
/TX1out: DD1.40 (RD2), R21.1
/TX2out: DD1.41 (RD3), R22.1
/USrx: DD1.1 (RC7), XP9.1
/UStx: DD1.44 (RC6), XP9.2
/U/Lsb: DD1.30 (RA7), R14.1
/XA: C3.2, DD2.2 (XA), Q1.2
/XB: DD2.3 (XB), Q1.1
GNDD: C1.1, C5.1.2, C5.2.2, C6.2, C7.2, C8.2, C9.2, C10.2, C11.2, C12.2, C13.2, C14.2, C15.2, C16.2, C17.2, C18.2, C19.2, C20.2, C21.2, C22.2, C23.2, C24.2, C25.2, C26.2, C27.2, C28.2, C29.2, C30.2, C31.2, C32.2, C33.2, C34.2, C35.2, C36.2, C37.2, C38.2, DA4.2 (GND), DD1.6 (GND), DD1.29 (GND), DD2.8 (GND), G1.2 (GND), R6.1, R7.1, R30.2, R32.2, R34.2, R37.2, R39.3, R39.2.2, XP1.5, XP3.4, XP4.2, XP5.3, XP6.2, XP7.2, XP8.3, XP9.3, XP10.3, XP11.5, XP12.6, XP13.3, XP14.2 (Ext), XP15.2 (Ext), XP16.2 (Ext)
unnamed: C3.1, G1.3 (OUT)
unnamed: C5.1.1, C5.2.1, DA1.1 (VI), VD3.1 (K)
unnamed: DA1.4 (ADJ), R29.2, R30.1
unnamed: DA2.4 (ADJ), R31.2, R32.1
unnamed: DA3.4 (ADJ), R33.2, R34.1
unnamed: DD2.4 (SCL), R40.1
unnamed: DD2.5 (SDA), R41.1
unnamed: R3.1, R4.2, R5.1, R6.2
unnamed: R7.2, XP1.4
unnamed: R8.1, XP2.1
unnamed: R9.1, XP2.2
unnamed: R10.1, XP2.3
unnamed: R11.1, XP2.4
unnamed: R13.1, VD1.2 (A)
unnamed: R28.1, VD2.1 (K)
unnamed: R36.2, R37.1, VD6.1 (A)
unnamed: VD1.1 (K), XP4.1

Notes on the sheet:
+3.3V
+5V

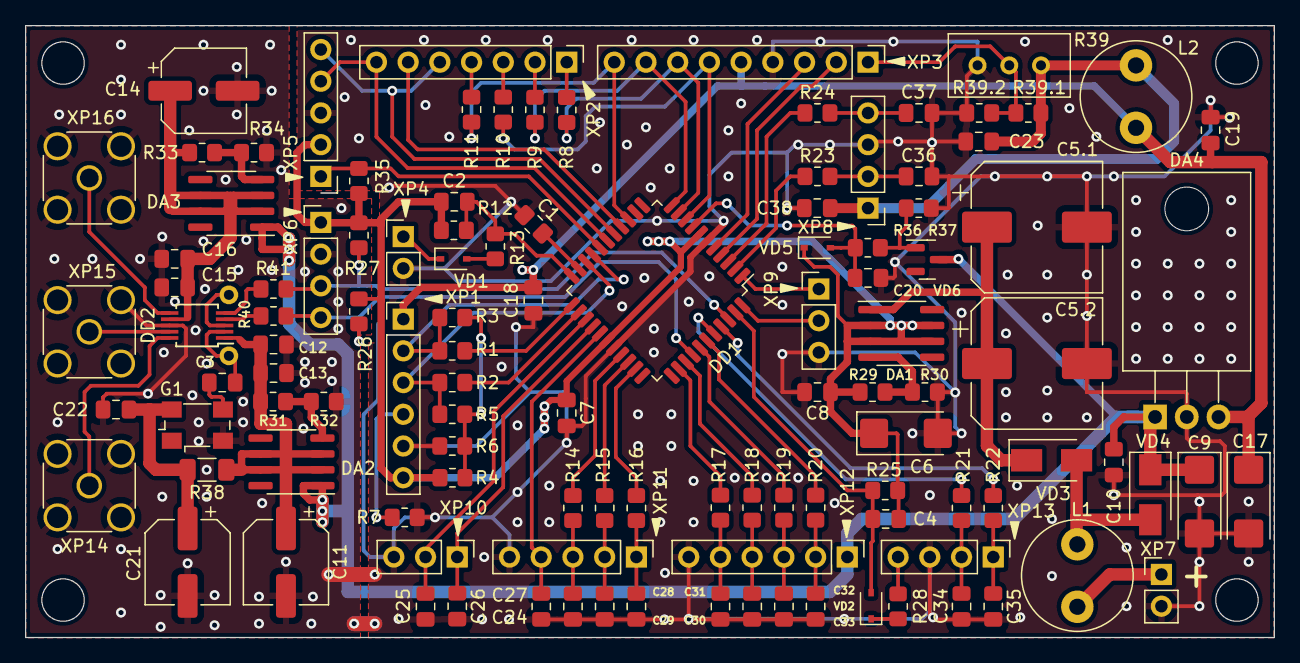
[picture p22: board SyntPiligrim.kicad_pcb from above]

Board: 2 copper layers, 100.0 x 49.0 mm, 114 parts (1 on the bottom side), 81 nets.
